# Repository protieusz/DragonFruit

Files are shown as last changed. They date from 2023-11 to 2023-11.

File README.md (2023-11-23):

# DragonFruit
Dragon Fruit, sponsored by [PCBWay](https://www.pcbway.com), a heavily modifed from AriaMelon's column staggered [Honey Dew](https://github.com/Ariamelon/Honeydew) powered by integrated RP2040 and Ariamelon's [Kiwano](https://github.com/Ariamelon/Kiwano) module.

# The DragonFruit is featured on https://kbd.news/DragonFruit-2178.html

This project is sponsored and made possible by:
PCBWay
Your one stop solution for PCB printing / PCBA service.  Top notch customer service. Their sales department are able to do a quick test after PCBA by plugging into the PC to see if the RP2040 storage containers popped up.
Best of all, all 5 PCBs assembled are all working and top notch soldering.  Their red silkscreen really pops out and matched with their yellow font silkscreen looks really nice. Thank you PCBWay!

## VIK Certification

This DragonFruit keyboard is VIK certified per Sadek of Fingerpunch's [VIK standard](https://github.com/sadekbaroudi/vik#keyboard-sample-cards). Read more about what VIK standard does to the custom keyboard with custom pointing devices like trackballs, trackpads,etc in Sadek's VIK standard in his [GitHub](https://github.com/sadekbaroudi/vik#keyboard-sample-cards).
| Category | Classification | Response |
| ---  | --- | --- |
| FPC connector | Required | :heavy_check_mark: |
| Breakout pins | Recommended | :x: |
| Supplies: SPI | Strongly recommended | :heavy_check_mark: |
| Supplies: I2C | Strongly recommended | :heavy_check_mark: |
| I2C on main PCB | Discouraged | no |
| I2C pull ups | Informative | N/A |
| Supplies: RGB | Strongly recommended | :heavy_check_mark: |
| Supplies: Extra GPIO 1 | Required | Digital only |
| Supplies: Extra GPIO 2 | Required | Digital only |

PCB print plus assembly has been tested and working correctly.  However please print at your own risk and no support will be given.  As for the Kiwano module, please go to AriaMelon's GITHUB to get the pcb printed and assembled.  The trackball 3DP files are all located in her GITHUB.  You would need the [specific](https://github.com/Ariamelon/Kiwano/tree/main/3DP) ones for this build and they are:

| Trackball 3DP Parts              | 
| ---------------------------------| 
| Trackball Mount Low Profile.step |                           
| Knob Ribbed.step                 |                      
| Knob Base.step                   |                                          

Only the gerber files of the DragonFruit will be uploaded to this GitHub. THe PCB design was done in EasyEDA so converting to KiCad pcb file format is a pain.  Case step file will also be uploaded and the pcb anchors for the case needs a 1mm offset since I forgot to adjust it so in order to fix it, I had to melt some of the plastic off in order to be able to slide the pcb into the case. ~~I will not update the case file anymore.~~ I have uploaded the fix step file so please use "DragonFruit Top Case Fixed.step" instead and ignore the other top case step file since I am too lazy to delete the whole directory and re-upload. Please do so at your own risk. No support will be given.

QMK code is borrowed from Aki27's [Bally](https://github.com/aki27kbd/vial-qmk/tree/vial/keyboards/aki27/bally) is working very smoothly.  I also uploaded my compiled QMK firmware. Trackball QMK code requires the QMK version above 0.19 in order to successful compiled. No support will be given for the code. Please ask the original designer/owner for support since I only copied and pasted the QMK code.

## Update: Nov 22, 2023. Keycap change.



## Update: Nov 7, 2023. Final Product.





85B45748A8880E51D3D014F1AD25B3F6







No PCB, fit test.




Fusion360







Printed Case




# License

</a></p>

You are free to:

Share — copy and redistribute the material in any medium or format

Adapt — remix, transform, and build upon the material

The licensor cannot revoke these freedoms as long as you follow the license terms.
Under the following terms:

Attribution — You must give appropriate credit, provide a link to the license, and indicate if changes were made. You may do so in any reasonable manner, but not in any way that suggests the licensor endorses you or your use.

NonCommercial — You may not use the material for commercial purposes.

ShareAlike — If you remix, transform, or build upon the material, you must distribute your contributions under the same license as the original.

No additional restrictions — You may not apply legal terms or technological measures that legally restrict others from doing anything the license permits.

DragonFruit by ProtieusKeebs is licensed under [CC BY-NC-SA 4.0](https://creativecommons.org/licenses/by-nc-sa/4.0/?ref=chooser-v1)

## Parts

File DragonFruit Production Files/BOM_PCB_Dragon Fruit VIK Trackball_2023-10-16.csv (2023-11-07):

ID | Name | Designator | Footprint | Quantity | Manufacturer Part | Manufacturer | Supplier | Supplier Part | Price | link
1 | 1uF | C1,C2,C5,C6,C9 | C0402 | 5 | CL05A105KA5NQNC | SAMSUNG(三星) | LCSC | C52923 | 0.004 | https://item.szlcsc.com/15869.html
2 | 22pF | C3,C4 | C0402 | 2 | 0402CG220J500NT | FH(风华) | LCSC | C1555 | 0.001 | https://item.szlcsc.com/15869.html
3 | 100nF | C7,C10,C11,C12,C13,C14,C15,C16 | C0402 | 8 | CL05B104KO5NNNC | SAMSUNG(三星) | LCSC | C1525 | 0.001 | https://item.szlcsc.com/15869.html
4 | 10uF | C8 | C0402 | 1 | CL05A106MQ5NUNC | SAMSUNG(三星) | LCSC | C15525 | 0.005 | https://item.szlcsc.com/15869.html
5 | 5.1kΩ | R3,R4,R5,R1,R2 | R0402 | 5 | 0402WGF5101TCE | UNI-ROYAL(厚声) | LCSC | C25905 | 0.001 | https://item.szlcsc.com/323315.html
6 | XC6206P332MR | U5 | SOT-23-3_L2.9-W1.6-P1.90-LS2.8-BR | 1 | XC6206P332MR | TOREX(特瑞仕) | LCSC | C5446 | 0.101 | https://item.szlcsc.com/14454.html
7 | PRTR5V0U2X,215 | D11 | SOT-143_L2.9-W1.3-P1.92-LS2.3-BR | 1 | PRTR5V0U2X,215 | Nexperia(安世) | LCSC | C12333 | 0.162 | https://item.szlcsc.com/280548.html
8 | BSMD0805-020-15V | F1 | F0805 | 1 | BSMD0805-020-15V | BHFUSE(佰宏) | LCSC | C883103 | 0.045 | https://item.szlcsc.com/343298.html
9 | 1kΩ | R6,R7 | R0402 | 2 | 0402WGF1001TCE | UNI-ROYAL(厚声) | LCSC | C11702 | 0.001 | https://item.szlcsc.com/323315.html
10 | RESET | U1 | RESET SWITCH | 1 |  |  |  |  |  | IGNORE, I will assemble on my own
11 | BOOT | U2 | RESET SWITCH | 1 |  |  |  |  |  | IGNORE, I will assemble on my own
12 | W25Q128JVSIQTR | U3 | SOIC-8_L5.3-W5.3-P1.27-LS8.0-BL | 1 | W25Q128JVSIQ | WINBOND(华邦) | LCSC | C97521 | 0.617 | https://item.szlcsc.com/63461.html
13 | RP2040 | U4 | LQFN-56_L7.0-W7.0-P0.4-EP | 1 | RP2040 | Raspberry Pi(树莓派) | LCSC | C2040 | 1.05 | https://atta.szlcsc.com/upload/public/pdf/source/20210621/C2040_96F425825606B7957D87DD32E2512CA9.pdf
14 | 12MHz | X1 | OSC-SMD_4P-L3.2-W2.5-BL | 1 | X322512MSB4SI | YXC(扬兴晶振) | LCSC | C9002 | 0.059 | https://item.szlcsc.com/15866.html
15 | TYPE-C-31-M-12 | USBC1 | USB-C_SMD-TYPE-C-31-M-12 | 1 | TYPE-C-31-M-12 | 韩国韩荣 | LCSC | C165948 | 0.216 | https://so.szlcsc.com/global.html?c=&k=C165948
16 | 27Ω | R8,R9 | R0402 | 2 | 0402WGF270JTCE | UNI-ROYAL(厚声) | LCSC | C25100 | 0.001 | https://item.szlcsc.com/323315.html
17 | FH12-12S-0.5SH(55) | FPC1 | FPC-SMD_FH12-12S-0.5SH-55 | 1 | FH12-12S-0.5SH(55) | HRS(广濑) | LCSC | C88360 | 0.428 | https://lcsc.com/eda_search?q=C88360&%26type=1&ref=editor
18 | SN74LVC1T45QDCKRQ1 | U6 | SC-70-6_L2.0-W1.3-P0.65-LS2.1-BR | 1 | SN74LVC1T45QDCKRQ1 | TI(德州仪器) | LCSC | C139353 | 0.263 | https://lcsc.com/eda_search?q=C139353&%26type=1&ref=editor
19 | SM4007PL | D000,D001,D002,D003,D004,D005,D006,D007,D008,D009,D100,D101,D102,D103,D104,D105,D106,D107,D108,D109,D200,D201,D202,D203,D204,D205,D206,D207,D208,D209,D301,D302,D303,D304,D305,D306,D307,D308 | SOD-123F_L2.8-W1.8-LS3.7-RD | 38 | SM4007PL | MDD | LCSC | C64898 | 0.007 | https://item.szlcsc.com/60254.html
20 | Switch | K000,K001,K002,K003,K004,K005,K006,K007,K008,K009,K100,K101,K102,K103,K104,K105,K106,K107,K108,K109,K200,K201,K202,K203,K204,K205,K206,K207,K208,K209,K301,K302,K303,K304,K305,K306,K307,K308 | CHERRY_MX_100_MILLMAX | 38 |  |  |  |  |  | IGNORE, I will assemble on my own

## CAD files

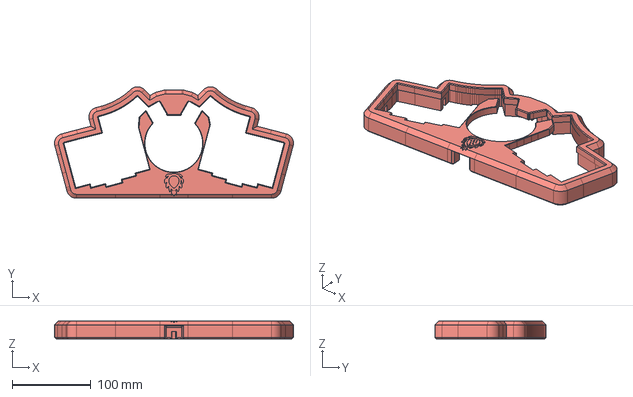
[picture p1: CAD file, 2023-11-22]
DragonFruit Production Files/DragonFruit Top Case Fixed.step
303.8 x 141.6 x 22.8 mm

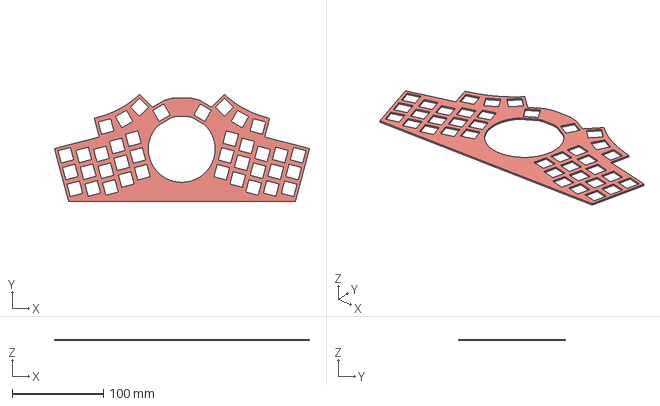
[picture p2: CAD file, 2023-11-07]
DragonFruit Production Files/DragonFruitSwitchPlate.step
279.8 x 117.7 x 1.50 mm

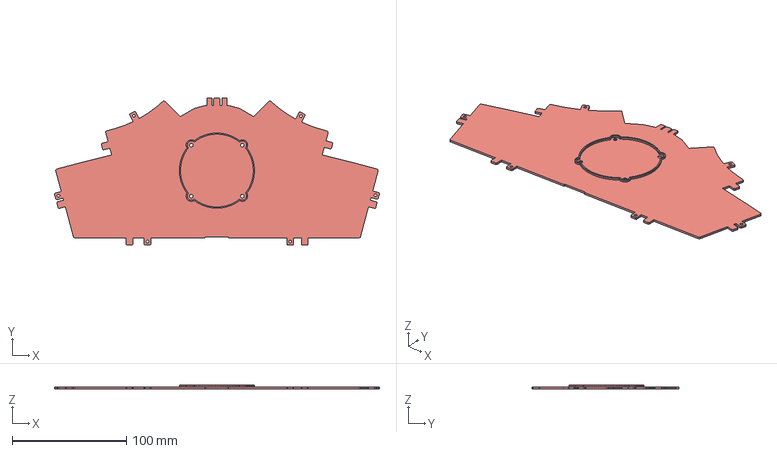
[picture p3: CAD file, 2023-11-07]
DragonFruit Production Files/DragonFruitBottomPlate.step
283.9 x 128.5 x 3.25 mm

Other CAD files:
DragonFruit Production Files/DragonFruitTopCase.step

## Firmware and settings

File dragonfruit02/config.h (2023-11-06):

// Copyright 2023 aki27 (@aki27kbd)
// SPDX-License-Identifier: GPL-2.0-or-later

#pragma once

//#define VIAL_KEYBOARD_UID {0xC4, 0x18, 0xCC, 0x6D, 0x1C, 0x16, 0x5B, 0x8D}
//#define VIAL_UNLOCK_COMBO_ROWS {0, 0}
//#define VIAL_UNLOCK_COMBO_COLS {1, 11}

/* VIA */
//#define DYNAMIC_KEYMAP_LAYER_COUNT 8


/* key matrix size */
//#define MATRIX_COLS 13
//#define MATRIX_ROWS 4


/* tapping term */
// #define TAPPING_FORCE_HOLD
//#define TAPPING_TERM 200
// #define IGNORE_MOD_TAP_INTERRUPT

#define RP2040_BOOTLOADER_DOUBLE_TAP_RESET // Activates the double-tap behavior
#define RP2040_BOOTLOADER_DOUBLE_TAP_RESET_TIMEOUT 200U // Timeout window in ms in which the double tap can occur.

#ifdef COMBO_ENABLE
#    define COMBO_COUNT 6
#    define COMBO_TERM 200
#endif

/* Encoder */
//#define ENCODERS_PAD_A { GP11 }
//#define ENCODERS_PAD_B { GP12 }
//#define ENCODER_RESOLUTION 4

/* Matrix*/
//#define MATRIX_COL_PINS { GP25, GP24, GP23, GP22, GP21, GP26, GP27, GP20, GP19, GP18, GP17, GP16, GP13 }
//#define MATRIX_ROW_PINS { GP28, GP10, GP14, GP15 }

/* COL2ROW, ROW2COL */
//#define DIODE_DIRECTION COL2ROW


/* Set 0 if debouncing isn't needed */
//#define DEBOUNCE 5


/* Mechanical locking support. Use KC_LCAP, KC_LNUM or KC_LSCR instead in keymap (Very Important for Scroll Lock!!!) */
#undef LOCKING_SUPPORT_ENABLE
/* Locking resynchronize hack */
#undef LOCKING_RESYNC_ENABLE


/* RGB LED */
//#define WS2812_PIO_USE_PIO1
#define WS2812_DI_PIN GP29

#ifdef RGBLIGHT_ENABLE
    #define RGBLED_NUM 8
    #define RGBLIGHT_LIMIT_VAL 80
    #define RGBLIGHT_HUE_STEP 10
    #define RGBLIGHT_SAT_STEP 17
    #define RGBLIGHT_VAL_STEP 17

    // #define RGBLIGHT_ANIMATIONS
    #define RGBLIGHT_EFFECT_BREATHING
    #define RGBLIGHT_EFFECT_RAINBOW_MOOD
    #define RGBLIGHT_EFFECT_RAINBOW_SWIRL
    #define RGBLIGHT_EFFECT_SNAKE
    #define RGBLIGHT_EFFECT_KNIGHT
    #define RGBLIGHT_EFFECT_CHRISTMAS
    #define RGBLIGHT_EFFECT_STATIC_GRADIENT
    #define RGBLIGHT_EFFECT_TWINKLE
    #define RGBLIGHT_EFFECT_ALTERNATING
#endif


/* Trackball */

#ifdef POINTING_DEVICE_ENABLE

//#    undef RP_SPI_USE_SPI0
//#    define RP_SPI_USE_SPI0 TRUE
//#    undef RP_SPI_USE_SPI1
//#    define RP_SPI_USE_SPI1 FALSE
#    define SPI_DRIVER SPID0

//#    define SPI_SCK_PIN GP22 //6
//#    define SPI_MISO_PIN GP24 //4
//#    define SPI_MOSI_PIN GP23 //7
#    define SPI_SCK_PIN GP18
#    define SPI_MISO_PIN GP16
#    define SPI_MOSI_PIN GP19

#endif


#ifndef PMW33XX_CS_PIN
#    define PMW33XX_CS_PIN GP17
#endif
#define POINTING_DEVICE_INVERT_X
#define POINTING_DEVICE_INVERT_Y
//#define ROTATIONAL_TRANSFORM_ANGLE 90
#define POINTING_DEVICE_ROTATION_180

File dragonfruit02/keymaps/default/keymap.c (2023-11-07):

/*
Copyright 2022 aki27

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
You should have received a copy of the GNU General Public License
along with this program.  If not, see <http://www.gnu.org/licenses/>.
*/

#include QMK_KEYBOARD_H

enum combo_events {
  COMBO_DEL,
  COMBO_ESC,
  COMBO_RCLICK,
  COMBO_LENGTH
};
uint16_t COMBO_LEN = COMBO_LENGTH;

const uint16_t PROGMEM combo_del[] = {KC_Y, KC_H, COMBO_END};
const uint16_t PROGMEM combo_esc[] = {KC_T, KC_G, COMBO_END};
const uint16_t PROGMEM combo_rclick[] = {KC_MS_BTN1, SCRL_MO, COMBO_END};

combo_t key_combos[] = {
  [COMBO_DEL] = COMBO(combo_del, KC_DEL),
  [COMBO_ESC] = COMBO(combo_esc, KC_ESC),
  [COMBO_RCLICK] = COMBO(combo_rclick, KC_MS_BTN2),
};

layer_state_t layer_state_set_user(layer_state_t state) {
    return update_tri_layer_state(state, 1, 2, 3);
} 

enum layer_names {
  _BASE,
  _FN1,
  _FN2,
  _FN3
};

const uint16_t PROGMEM keymaps[][MATRIX_ROWS][MATRIX_COLS] = {
    
    [_BASE] = LAYOUT(
        KC_Q,         KC_W, KC_E,    KC_R,    KC_T,                                           KC_Y,          KC_U,          KC_I,     KC_O,   KC_P,
        KC_A,         KC_S, KC_D,    KC_F,    KC_G,                                           KC_H,          KC_J,          KC_K,     KC_L,   KC_SCLN,
        LSFT_T(KC_Z), KC_X, KC_C,    KC_V,    KC_B,                                           KC_N,          KC_M,          KC_COMMA, KC_DOT, RSFT_T(KC_SLSH),
                            KC_LCTL, KC_LGUI, LT(1,KC_BSPC),   KC_MS_BTN1,    SCRL_MO,     LT(2,KC_SPC),   (KC_ENT),      KC_LALT
    ),
    [_FN1] = LAYOUT(
        KC_1,    KC_2,    KC_3,    KC_4,    KC_5,                            KC_6,     KC_7,    KC_8,    KC_9,    KC_0,
        KC_TAB,  _______, _______, _______, _______,                         KC_MINS,  KC_EQL,  KC_LBRC, KC_RBRC, KC_QUOT,
        _______, _______, KC_MUTE, KC_VOLD, KC_VOLU,                         KC_TILD,  KC_GRV,  _______, _______, KC_BSLS,
                          _______, _______, _______,     _______, _______,   _______,  _______, _______
    ),
    [_FN2] = LAYOUT(
        KC_EXLM, KC_AT,   KC_HASH, KC_DLR,  KC_PERC,                         KC_CIRC, KC_AMPR, KC_ASTR, KC_LPRN, KC_RPRN,
        RGB_VAI,  RGB_SAI,    RGB_HUI,    RGB_SPI,   RGB_MOD,                RGB_TOG,  _______,  _______,   _______, _______,
        RGB_VAD,  RGB_SAD,    RGB_HUD,    RGB_SPD,   RGB_RMOD,               _______,  _______, _______, _______, _______,
                          _______, _______, _______,     _______, _______,   _______,  _______, _______
    ),
    [_FN3] = LAYOUT(
        _______, KC_UP, _______, _______, _______,                         KC_F1,   KC_F2,   KC_F3,   KC_F4,   KC_PSCR,
        KC_LEFT, KC_DOWN, KC_RIGHT, _______, _______,                      KC_F5,   KC_F6,   KC_F7,   KC_F8,   KC_F9,
        _______, _______, ROT_L15, ROT_R15, CPI_SW,                       KC_F10,  KC_F11,  KC_F12,  _______, _______,
                          _______, _______, _______,     _______, _______,   _______, _______, _______
    )
};

//bool encoder_update_user(uint8_t index, bool clockwise) {
    //if (index == 0) {
        //if (clockwise) {
            //tap_code(KC_VOLD);
            //tap_code(KC_MS_WH_UP);
        //} else {
            //tap_code(KC_VOLU);
            //tap_code(KC_MS_WH_DOWN);
        //}
    //}
    //return true;
//}

#if defined(ENCODER_MAP_ENABLE)
const uint16_t PROGMEM encoder_map[][NUM_ENCODERS][2] = {
    [0] =  { ENCODER_CCW_CW(KC_MS_WH_UP, KC_MS_WH_DOWN)  },
    [1] =  { ENCODER_CCW_CW(KC_MS_WH_LEFT, KC_MS_WH_RIGHT)  },
    [2] =  { ENCODER_CCW_CW(KC_PGUP, KC_PGDN)  },
    [3] =  { ENCODER_CCW_CW(KC_VOLD, KC_VOLU)  } 
    //[4] =  { ENCODER_CCW_CW(XXXXXXX, XXXXXXX) }
};
#endif

//keyevent_t encoder1_ccw = {
    //.key = (keypos_t){.row = 3, .col = 0},
    //.pressed = false
//};

//keyevent_t encoder1_cw = {
    //.key = (keypos_t){.row = 3, .col = 9},
    //.pressed = false
//};

//bool encoder_update_user(uint8_t index, bool clockwise) {
    //if (index == 0) { /* First encoder */
        //if (clockwise) {
            //encoder1_cw.pressed = true;
            //encoder1_cw.time = (timer_read() | 1);
            //action_exec(encoder1_cw);
        //} else {
            //encoder1_ccw.pressed = true;
            //encoder1_ccw.time = (timer_read() | 1);
            //action_exec(encoder1_ccw);
        //}
    //}

    //return true;
//}

//void matrix_scan_user(void) {

    //if (IS_PRESSED(encoder1_ccw)) {
        //encoder1_ccw.pressed = false;
        //encoder1_ccw.time = (timer_read() | 1);
        //action_exec(encoder1_ccw);
    //}

    //if (IS_PRESSED(encoder1_cw)) {
        //encoder1_cw.pressed = false;
        //encoder1_cw.time = (timer_read() | 1);
        //action_exec(encoder1_cw);
    //}

//}

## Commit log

2023-11-07 Gerbers, STEP, BOM, Components placement
    [BOM_PCB_Dragon Fruit VIK Trackball_2023-10-16.csv, DragonFruitBottomPlate.step, DragonFruitSwitchPlate.step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]
2023-11-22 Fixed for PCB anchors
    [DragonFruit Top Case Fixed.step]

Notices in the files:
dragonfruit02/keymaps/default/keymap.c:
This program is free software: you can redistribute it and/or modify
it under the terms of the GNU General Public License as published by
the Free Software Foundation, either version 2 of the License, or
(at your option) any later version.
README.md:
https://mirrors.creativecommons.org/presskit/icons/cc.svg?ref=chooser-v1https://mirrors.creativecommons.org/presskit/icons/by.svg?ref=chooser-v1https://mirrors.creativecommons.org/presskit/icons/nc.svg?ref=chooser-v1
